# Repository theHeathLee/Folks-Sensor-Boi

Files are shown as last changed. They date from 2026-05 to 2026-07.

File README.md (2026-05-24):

# Folks Sensor Boi

> Multi-sensor engine telemetry unit for gasoline vehicles. Collects six engine parameters and transmits them wirelessly to a companion app and over CAN bus.

---

## Overview

A compact, sealed sensor interface box designed to mount in the engine bay of a classic or modified gasoline vehicle. Built around the ESP32-WROOM-S3.

Designed for JLCPCB fabrication and SMT assembly. 

---

## Features

| Channel | Sensor / method | Interface |
|---|---|---|
| Exhaust / CHT temperature | K-type thermocouple (galvanically isolated) | SPI — MAX31856 |
| Engine RPM | Ignition coil primary (optocoupled) | GPIO interrupt |
| Wheel speed | Hall effect sensor + Schmitt trigger | GPIO interrupt |
| Oil temperature | NTC sender (VDO-type) | ADC |
| Manifold vacuum / MAP | MPXHZ6115A6T1 15–115 kPa | ADC |
| Battery voltage | Resistor divider | ADC |

**Outputs**
- WiFi 802.11 b/g/n (AP mode) + BLE 4.2 → companion app
- CAN 2.0B @ 500 kbit/s via SN65HVD230

**Programming**
- USB-C (CP2102N) with auto-reset circuit — no manual BOOT/EN required

---

## Schematic

<!-- schematic-start -->
Schematic
<!-- schematic-end -->

---

## Hardware

### MCU
- **ESP32-WROOM-32U-N4** — dual-core 240 MHz, WiFi, BLE, TWAI CAN, SPI, 12-bit ADC
- External u.FL antenna for full-vehicle wireless range

---
)

```
├── hardware/
│   ├── engine-sensor-box.kicad_pro
│   ├── engine-sensor-box.kicad_sch
│   ├── engine-sensor-box.kicad_pcb
│   ├── sym-lib-table
│   ├── fp-lib-table
│   └── jlcimport/               # project-local imported symbols + footprints
├── production/
│   ├── gerbers/
│   ├── bom.csv                  # JLCPCB-format BOM
│   └── positions.csv            # CPL file
├── docs/
│   └── engine_sensor_box_BOM.xlsx
└── README.md
```

---

## BOM

<!-- bom-start -->
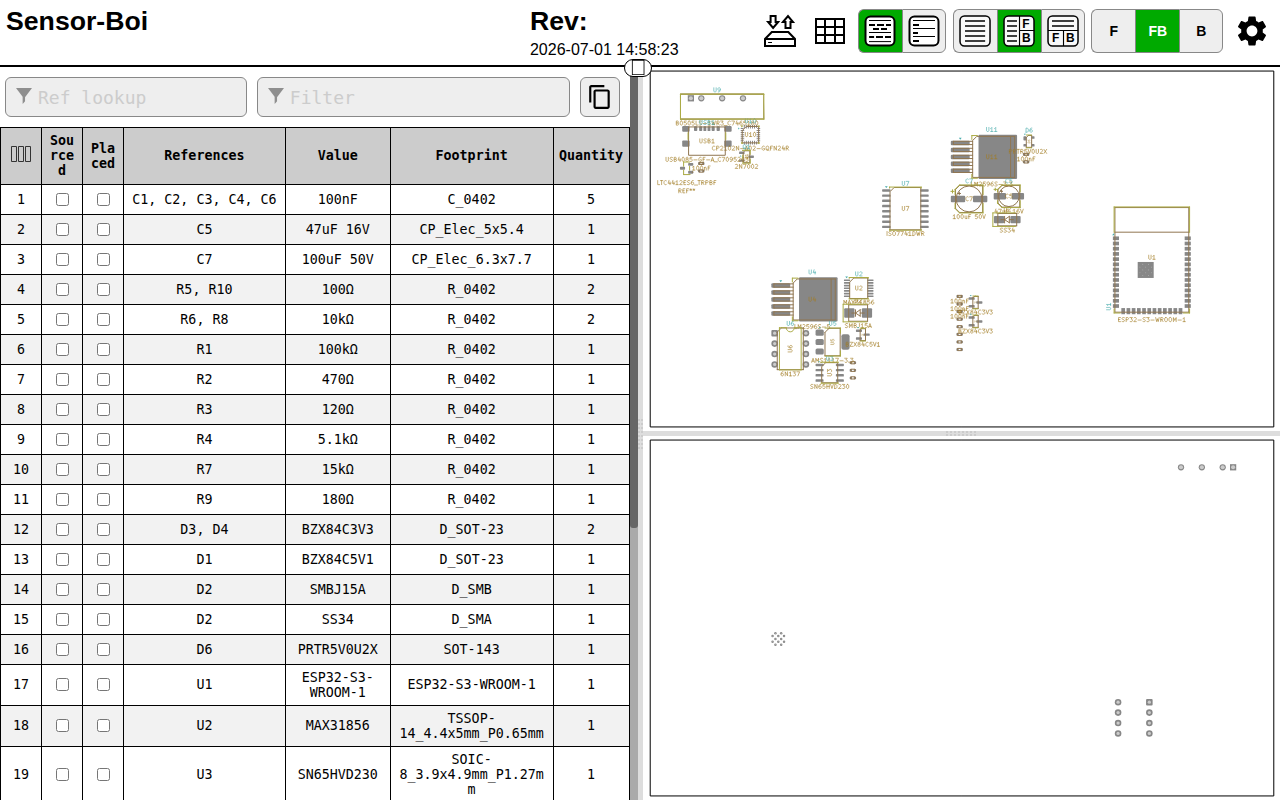
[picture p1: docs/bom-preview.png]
Interactive BOM


[Open interactive BOM →](https://theheathlee.github.io/Folks-Sensor-Boi/bom.html)
<!-- bom-end -->

Full BOM with LCSC part numbers, stock status, unit costs, and placement tracking is in [`engine_sensor_box_BOM.xlsx`](engine_sensor_box_BOM.xlsx).

---

## Firmware

> Firmware repository: _link TBD_

---

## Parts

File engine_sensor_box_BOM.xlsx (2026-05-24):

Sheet: BOM
Engine Sensor Box — Master BOM
Rev 0.1 | Subs applied: ADUM3401→ISO7741DWR · MPX4115AP→MPXHZ6115A6T1
Subsystem | Designator | Part / Value | Qty | Package | LCSC # | Supply status | Est. stock | Unit cost (€) | Ext cost (€) | Purpose / notes | Placed? | Placement notes
MCU
MCU | U1 | ESP32-WROOM-32U-N4 | 1 | SMD 18×19.2mm | C328062 | In stock | 2 000+ | €3.50 | €3.50 | Main MCU — dual-core 240 MHz, WiFi, BLE, TWAI CAN, SPI, 12-bit ADC, u.FL antenna | ☐
THERMOCOUPLE
Thermocouple | U2 | MAX31856MUD+T | 1 | MSOP-10 | C2653162 | Watch | ~1 980 | €6.00 | €6.00 | Thermocouple amplifier — SPI, cold-junction comp, 50/60 Hz notch filter, K-type | ☐
Thermocouple | U3 | ISO7741DWR | 1 | SOIC-16 | C571196 | Swapped | 5 742 | €0.86 | €0.86 | 4-ch digital isolator — galvanic SPI isolation (sub for ADUM3401ARWZ, pin-compat) | ☐
Thermocouple | U4 | B0505LS-1WR3 | 1 | SIP-4 | C7465180 | In stock | 7 932 | €0.40 | €0.40 | Isolated 5V DC-DC — powers thermocouple side independently from main GND | ☐
RPM
RPM | U5 | 6N137S | 1 | SOIC-8 | C6553 | In stock | 10 000+ | €0.45 | €0.45 | High-speed optocoupler — isolates ignition coil transients from MCU logic | ☐
RPM | D1 | P6KE15A | 1 | DO-214AA | C514442 | In stock | 5 000+ | €0.25 | €0.25 | 1.5 kW TVS — first-stage spike clamp on ignition coil input | ☐
RPM | D2 | BZX84C5V1 | 1 | SOT-23 | C181144 | Basic part | 100 000+ | €0.05 | €0.05 | 5.1V zener — clamps ignition input before 6N137 LED drive resistor | ☐
RPM | R1 | 100 kΩ 0402 | 1 | 0402 | — | Basic part | ∞ | €0.01 | €0.01 | Pull-up on 6N137 collector output to 3.3V | ☐
RPM | R2 | 470 Ω 0402 | 1 | 0402 | — | Basic part | ∞ | €0.01 | €0.01 | Current-limiting resistor for 6N137 LED input | ☐
WHEEL SPEED
Wheel speed | U6 | AH3144E-SA-7-B | 1 | TO-92S | C10681 | Separate | 10 000+ | €0.35 | €0.35 | Hall sensor — open-collector, remote-mounted at wheel. Order sep, hand-solder. | ☐
Wheel speed | U7 | 74LVC1G14GW | 1 | SOT-353 | C155655 | Basic part | 50 000+ | €0.15 | €0.15 | Schmitt trigger — cleans noisy edges from long cable run, 0.6V hysteresis | ☐
Wheel speed | D3 | PRTR5V0U2X,215 | 1 | SOT-363 | C12333 | Basic part | 20 000+ | €0.10 | €0.10 | Dual TVS ESD array — clamps wheel speed GPIO input line | ☐
Wheel speed | R3 | 10 kΩ 0402 | 1 | 0402 | — | Basic part | ∞ | €0.01 | €0.01 | Hall sensor pull-up at sensor end, biases open-collector output | ☐
Wheel speed | R4 | 100 Ω 0402 | 1 | 0402 | — | Basic part | ∞ | €0.01 | €0.01 | Series filter resistor at PCB entry — fc ≈ 16 kHz with C1 | ☐
Wheel speed | C1 | 100 nF 0402 X7R | 1 | 0402 | C307331 | Basic part | ∞ | €0.01 | €0.01 | RC filter bypass cap — paired with R4, kills ignition-band noise | ☐
ANALOG
Analog | U8 | MPXHZ6115A6T1 | 1 | SOP-8 | C3235759 | Swapped | 348 | €4.39 | €4.39 | MAP sensor 15–115 kPa SMD — JLCPCB assemblable (sub for MPX4115AP DIP) | ☐
Analog | R5 | 1 kΩ 0402 | 1 | 0402 | — | Basic part | ∞ | €0.01 | €0.01 | Series RC filter on MAP output — fc ≈ 16 kHz | ☐
Analog | R6 | 10 kΩ 0402 | 1 | 0402 | — | Basic part | ∞ | €0.01 | €0.01 | MAP voltage divider top — scales 4.7V max to ≤3.3V for ESP32 ADC | ☐
Analog | R7 | 18 kΩ 0402 | 1 | 0402 | — | Basic part | ∞ | €0.01 | €0.01 | MAP voltage divider bottom | ☐
Analog | C2 | 10 nF 0402 | 1 | 0402 | — | Basic part | ∞ | €0.01 | €0.01 | RC filter cap on MAP output | ☐
Analog | C3 | 100 nF 0402 X7R | 1 | 0402 | C307331 | Basic part | ∞ | €0.01 | €0.01 | ADC bypass cap at MAP divider midpoint | ☐
Analog | R8 | 180 Ω 1% 0402 | 1 | 0402 | — | Basic part | ∞ | €0.02 | €0.02 | NTC oil temp upper divider — precision 1% for R-T conversion accuracy | ☐
Analog | R9 | 100 kΩ 1% 0402 | 1 | 0402 | — | Basic part | ∞ | €0.02 | €0.02 | Battery voltage divider top — scales 0–15V to 0–2.6V for ADC | ☐
Analog | R10 | 22 kΩ 1% 0402 | 1 | 0402 | — | Basic part | ∞ | €0.02 | €0.02 | Battery voltage divider bottom | ☐
Analog | D4 | BZX84C3V3 | 1 | SOT-23 | C181141 | Basic part | 100 000+ | €0.05 | €0.05 | 3.3V zener — hard clamp on battery voltage ADC pin | ☐
CAN
CAN | U9 | SN65HVD230DR | 1 | SOIC-8 | C113987 | In stock | 10 000+ | €0.60 | €0.60 | 3.3V CAN transceiver — ISO 11898, pairs directly with ESP32 TWAI | ☐
CAN | D5 | PESD2CAN,215 | 1 | SOT-363 | C154297 | In stock | 15 000+ | €0.25 | €0.25 | Dual-line CAN ESD protection — clamps CANH and CANL | ☐
CAN | R11 | 120 Ω 0402 | 1 | 0402 | — | Basic part | ∞ | €0.01 | €0.01 | CAN bus termination — populate only if this node is a bus endpoint | ☐
POWER
Power | U10 | LM2596S-5.0 | 1 | SOP-8 | C347553 | In stock | 5 000+ | €0.80 | €0.80 | 3A step-down buck — 12V→5V at ~87% efficiency, main power stage | ☐
Power | U11 | AMS1117-3.3 | 1 | SOT-223 | C347222 | Basic part | 500 000+ | €0.20 | €0.20 | 800mA LDO — 5V→3.3V post-regulator, rejects buck switching noise | ☐
Power | L1 | 100 µH SWPA8040S | 1 | SMD 8×8mm | C408544 | In stock | 3 000+ | €0.40 | €0.40 | Buck inductor — 4A rated, energy storage element for LM2596S | ☐
Power | D6 | SS14 | 2 | DO-214AC | C2480 | Basic part | 500 000+ | €0.10 | €0.20 | Schottky OR-ing diodes — 12V buck and USB 5V rails, no contention | ☐
Power | D7 | SMBJ15A | 1 | DO-214AA | C15092 | In stock | 20 000+ | €0.30 | €0.30 | TVS input clamp — absorbs automotive load dump transients to ~30V | ☐
Power | Q1 | IRF9540N | 1 | TO-220 | C338461 | Separate | 2 000+ | €0.35 | €0.35 | P-ch MOSFET reverse polarity — zero drop, 23A. TO-220, hand-solder. | ☐
Power | C4 | 220 µF 25V elec. | 1 | Through-hole | C80574 | Separate | 10 000+ | €0.15 | €0.15 | Buck output bulk cap — smooths 5V rail ripple. Through-hole, hand-solder. | ☐
Power | C5 | 10 µF 0603 X5R | 2 | 0603 | C19702 | Basic part | ∞ | €0.03 | €0.06 | LDO input and output caps — AMS1117 stability requirement | ☐
Power | C6 | 100 nF 0402 X7R | 4 | 0402 | C307331 | Basic part | ∞ | €0.01 | €0.04 | High-freq bypass — both sides of AMS1117 and ESP32 VCC pins | ☐
Power | R12 | 100 kΩ 0402 | 1 | 0402 | — | Basic part | ∞ | €0.01 | €0.01 | IRF9540 gate pull-down — biases MOSFET on at power-up | ☐
Power | D8 | 1N5822 | 1 | DO-201 | C35722 | Separate | 5 000+ | €0.15 | €0.15 | Buck freewheeling diode — low Vf fast recovery. DO-201, hand-solder. | ☐
USB
USB | U12 | CP2102N-A02-GQFN24R | 1 | QFN-24 | C969151 | In stock | 2 000+ | €1.37 | €1.37 | USB-to-UART bridge — programs ESP32 over USB-C, 3.3V native IO | ☐
USB | J1 | USB4085-GF-A | 1 | SMD | C7095263 | In stock | 1 766 | €0.81 | €0.81 | USB-C connector — USB 2.0, robust shell, firmware programming port | ☐
USB | Q2 | 2N7002 | 2 | SOT-23 | C8545 | Basic part | 500 000+ | €0.02 | €0.04 | Auto-reset MOSFETs — CP2102N RTS/DTR drives EN/GPIO0 for bootloader entry | ☐
USB | R13 | 5.1 kΩ 0402 | 2 | 0402 | — | Basic part | ∞ | €0.01 | €0.02 | USB-C CC pull-downs — mandatory for host to supply 5V/500mA | ☐
USB | C7 | 100 nF 0402 X7R | 2 | 0402 | C307331 | Basic part | ∞ | €0.01 | €0.02 | Decoupling on CP2102N VDD and VBUS pins | ☐
MECHANICAL
Mechanical | — | IP65 ABS enclosure | 1 | — | — | Separate | — | €7.00 | €7.00 | Sealed enclosure — protects PCB from oil, water, engine-bay vibration | ☐
Mechanical | — | Cable glands M12 ×4 | 4 | — | — | Separate | — | €0.50 | €2.00 | Waterproof cable entry — power, CAN, sensors, antenna | ☐
Mechanical | — | u.FL to SMA pigtail | 1 | — | — | Separate | — | €1.50 | €1.50 | Antenna extension cable — routes ESP32 RF to SMA on enclosure wall | ☐
Mechanical | — | 2.4 GHz ext. antenna | 1 | — | — | Separate | — | €2.00 | €2.00 | External WiFi/BLE antenna — full-vehicle wireless range | ☐
Mechanical | — | Deutsch DT connectors | 1 | — | — | Separate | — | €5.00 | €5.00 | Automotive IP67 connectors — vibration-proof, motorsport standard | ☐
Mechanical | — | PCB 4-layer JLCPCB | 1 | — | — | Separate | — | €4.50 | €4.50 | 4-layer stackup signal/GND/PWR/signal — 100-piece run | ☐
Mechanical | — | Conformal coat + label | 1 | — | — | Separate | — | €1.00 | €1.00 | Moisture protection and product identification | ☐
TOTAL BOM COST (per unit, 100-piece run) |  |  |  |  |  |  |  |  | €45.49

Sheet: Legend
LEGEND
Supply status | Meaning
In stock | Healthy LCSC stock — ready for production run
Watch | Low stock (<2 000 units) — set LCSC stock alert
Swapped | Original part substituted — see Purpose column for rationale
Separate | Not JLCPCB SMT assembled — order separately, hand-solder
Basic part | JLCPCB pre-loaded feeder — no extra setup fee
Placed? | Mark ✓ when placed in KiCad schematic
Placement notes | Record sheet, refdes, or deviations from BOM

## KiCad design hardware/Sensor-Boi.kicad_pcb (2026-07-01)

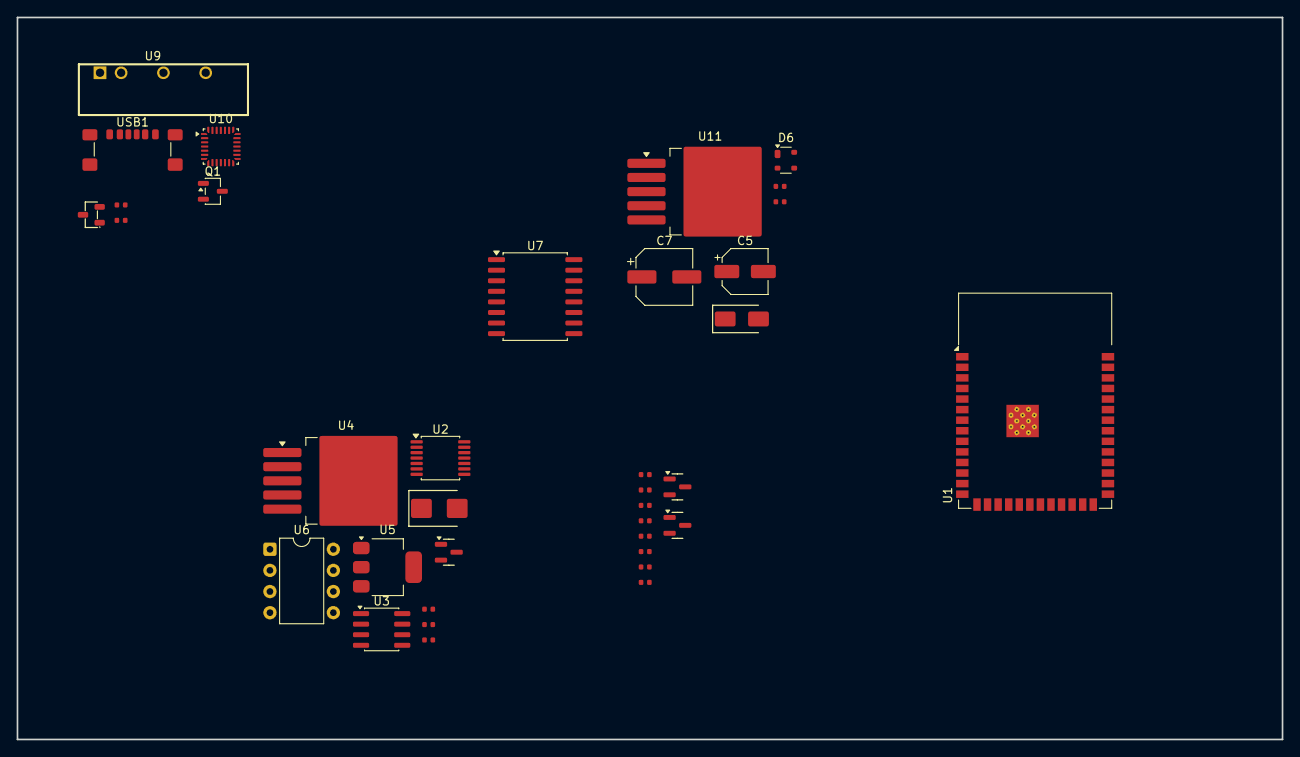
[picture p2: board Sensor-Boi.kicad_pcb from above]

Board: 2 copper layers, 152.0 x 86.8 mm, 36 parts (0 on the bottom side), 19 nets, no tracks yet.

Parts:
C1, C2, C3, C4, C6: 100nF; C_0402
C5: 47uF 16V; CP_Elec_5x5.4
C7: 100uF 50V; CP_Elec_6.3x7.7
D1: BZX84C5V1; D_SOT-23
D2: SMBJ15A; D_SMB
D2#2: SS34; D_SMA
D3, D4: BZX84C3V3; D_SOT-23
D6: PRTR5V0U2X; SOT-143
Q1: 2N7002; SOT-23-3
R1: 100kΩ; R_0402
R2: 470Ω; R_0402
R3: 120Ω; R_0402
R4: 5.1kΩ; R_0402
R5, R10: 100Ω; R_0402
R6, R8: 10kΩ; R_0402
R7: 15kΩ; R_0402
R9: 180Ω; R_0402
U1: ESP32-S3-WROOM-1
U2: MAX31856; TSSOP-14_4.4x5mm_P0.65mm
U3: SN65HVD230; SOIC-8_3.9x4.9mm_P1.27mm
U4: LM2596S-5; TO-263-5_TabPin3
U5: AMS1117-3.3; SOT-223-3_TabPin2
U6: 6N137; DIP-8_W7.62mm
U7: ISO7741DWR; SOIC-16W_7.5x10.3mm_P1.27mm
U8: LTC4412ES6_TRPBF; SOT-23-3_L2.9-W1.3-P0.95-LS2.4-BR
U9: B0505LS-1WR3_C7465180
U10: CP2102N-A02-GQFN24R; QFN-28_4x4mm_P0.5mm
U11: LM2596S-3.3; TO-263-5_TabPin3
USB1: USB4085-GF-A_C7095263; USB_C_Receptacle_GCT_USB4135-GF-A_6P_TopMnt_Horizontal

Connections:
/3V3: C5.1, D6.4 (VCC), R9.2, U1.2 (3V3), U3.3 (VCC), U5.2 (VO), U7.16 (VCC2), U9.1 (VIN), U11.4 (FB)
/3V3_Isolated: U2.5 (AVDD), U2.8 (DVDD), U7.1 (VCC1), U9.6 (+Vo)
/12V: C7.1, U11.1 (VIN)
/CAN_H: R3.1, U3.7 (CANH)
/CAN_L: R3.2, U3.6 (CANL)
/CAN_RX: U1.10 (IO17), U3.4 (R)
/CAN_TX: U1.11 (IO18), U3.1 (D)
/Hall_Sensor: C6.1, R10.1
/Lambda_MCU: C2.1, D3.1, R6.2, R7.1, U1.6 (IO6)
/MAP_Signal_MCU: C3.1, D4.1, R8.2, U1.39 (IO1)
/OIL_MCU: C4.1, R9.1, U1.38 (IO2)
/TEMP_SCK: U2.10 (SCK), U7.3 (INA)
/TEMP_SDI: U2.12 (SDI), U7.5 (INC)
/TEMP_SDO: U2.11 (SDO), U7.4 (INB)
GND: C2.2, C3.2, C4.2, C5.2, C7.2, D2#2.1, D4.3, D6.1 (GND), R7.2, U1.1 (GND), U1.40 (GND), U1.41 (GND), U3.2 (GND), U4.3 (GND_3), U5.1 (GND), U7.15 (GND2), U8.2 (GND_2), U9.2 (GND), U11.3 (GND), U11.5 (~ON/OFF)
GND2: U2.1 (AGND), U2.14 (DGND), U7.2 (GND1), U9.4 (0V)
unnamed: D6.2 (I/O1), R10.2
unnamed: R5.2, R6.1
unnamed: D2#2.2, U11.2 (OUT)

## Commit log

2026-05-24 Add .gitignore for KiCad and macOS
2026-05-24 add a majority of symbols to schematic
    [Sensor-Boi.kicad_pcb, Sensor-Boi.kicad_sch, engine_sensor_box_BOM.xlsx]
2026-05-24 Rename project from 'Engine Sensor Box' to 'Folks Sensor Boi'
2026-05-24 ci: switch KiBot to v2_dk10 — kicad10_auto_full:latest not yet published
    The v2_k10 action tag references ghcr.io/inti-cmnb/kicad10_auto_full:latest
    which does not exist on GHCR. The v2_dk10 tag uses the :dev variant of the
    same KiCad 10 image, which is available.
2026-05-24 ci: split KiBot into two steps, make iBOM continue-on-error
    iBOM requires a board outline on Edge.Cuts which hasn't been drawn yet.
    Split schematic SVG and iBOM into separate steps so the SVG commits
    successfully while iBOM fails gracefully until the outline is added.
2026-05-24 ci: replace auto-commit action with manual git step to handle missing bom.html
    git-auto-commit-action exits 128 if a listed file doesn't exist; since iBOM
    is continue-on-error, bom.html may not be produced. Use a plain git step
    that only stages files that are present.
2026-05-24 ci: regenerate schematic and BOM [skip ci]
2026-05-24 ci: deploy iBOM to GitHub Pages, add screenshot preview in README
    - Enable GitHub Pages (Actions-based deployment)
    - Add Chrome headless screenshot of bom.html → docs/bom-preview.png
    - README BOM section: clickable screenshot → live GitHub Pages URL
    (iframes are stripped by GitHub's markdown renderer; screenshot link
    is the closest equivalent)
    - Add docs/index.html landing page served from Pages
    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
2026-05-24 ci: don't link to bom.html until it actually exists
    README and Pages index now show a placeholder message when bom.html
    hasn't been generated yet, instead of a live link that 404s.
2026-05-24 add outline to pcb
    [Sensor-Boi.kicad_pcb, Sensor-Boi.kicad_sch]
2026-06-23 add some connections
    [Sensor-Boi.kicad_sch]
2026-06-23 add power electronics and connections
    [Sensor-Boi.kicad_pcb, Sensor-Boi.kicad_sch]
2026-07-01 complete power subsystem
    [Sensor-Boi.kicad_pcb, Sensor-Boi.kicad_sch]
